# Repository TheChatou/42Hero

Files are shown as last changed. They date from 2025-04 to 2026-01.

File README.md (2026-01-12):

# 42Hero  
*Borne d’arcade rythmique embarquée — jeu physique, musique 8-bit, fabrication réelle.*
<p align="center">
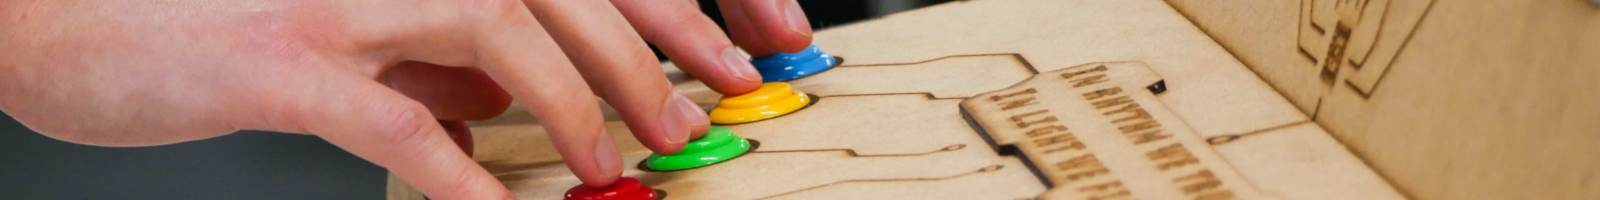
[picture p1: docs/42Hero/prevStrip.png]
  
</p>
---

## 42Hero ?

42Hero est né au sein du **LabElec (42Chips)**, à l’occasion de la grande soirée d’inauguration du nouveau campus **42 Paris – 42Up**.

Lors d’une réunion du Lab, plusieurs idées de projets sont évoquées.  
Je n’ai, en théorie, pas le temps de m’engager sur un projet hors cursus.  
Mais cette idée-là reste sans volontaire.

Je lève la main.  
Puis, dans la semaine, deux camarades me rejoignent. Le projet est lancé.

L’idée est simple :  
prendre l’ADN de **Guitar Hero** et l’adapter à un **format arcade physique**, sans écran.

42Hero est une **mini-borne d’arcade rythmique deux joueurs**, conçue pour une seule chose :  
être **jouable immédiatement**, sans explication, sans friction.

- jouable en quelques secondes  
- lisible sans tutoriel  
- robuste face à un vrai public  
- amusante à jouer *et* à regarder  

La boucle de jeu est volontairement minimale :

> **appuyer au bon moment → voir et entendre immédiatement le résultat**

Aucune interface graphique, aucun menu complexe :  
tout passe par le **son**, les **LEDs** et le **rythme**.

Le projet met l’accent sur l’**expérience utilisateur physique**, la synchronisation temps réel et la fiabilité — pas sur une complexité logicielle décorative.

---

## Mon rôle & implications techniques

42Hero est un **projet embarqué de l’École 42**, réalisé en équipe de trois, avec une contrainte simple et brutale :  
**une deadline réelle, du public, et zéro droit à l’erreur visible**.

J’ai assuré une **grande partie de la direction technique et de l’expérience de jeu**, avec un objectif clair :  
**livrer une borne stable, lisible et fun**, pas un prototype “qui marche chez moi”.

Mon rôle a couvert :

- **Direction de conception de la borne** (forme, ergonomie, lisibilité)
- **Logique centrale de gameplay** (states, scoring, timing)
- **Système musical embarqué** : adaptation / réécriture de morceaux et intégration microcontrôleur
- **UX physique** : boutons, feedback LEDs, rythme, compréhension instantanée
- **Fabrication & intégration** : itérations, contraintes matérielles, tests réels

Ce projet a impliqué un **investissement massif sur une période courte**, au prix d’une quasi mise en pause de mon cursus commun — choix discutable, mais formateur.

En résumé :  
du **frontend**, sans écran, avec des fils, de la soudure…  
et une deadline qui ne négociait pas.

---

## Aperçu — Une vraie borne, pas une démo

<p align="center">
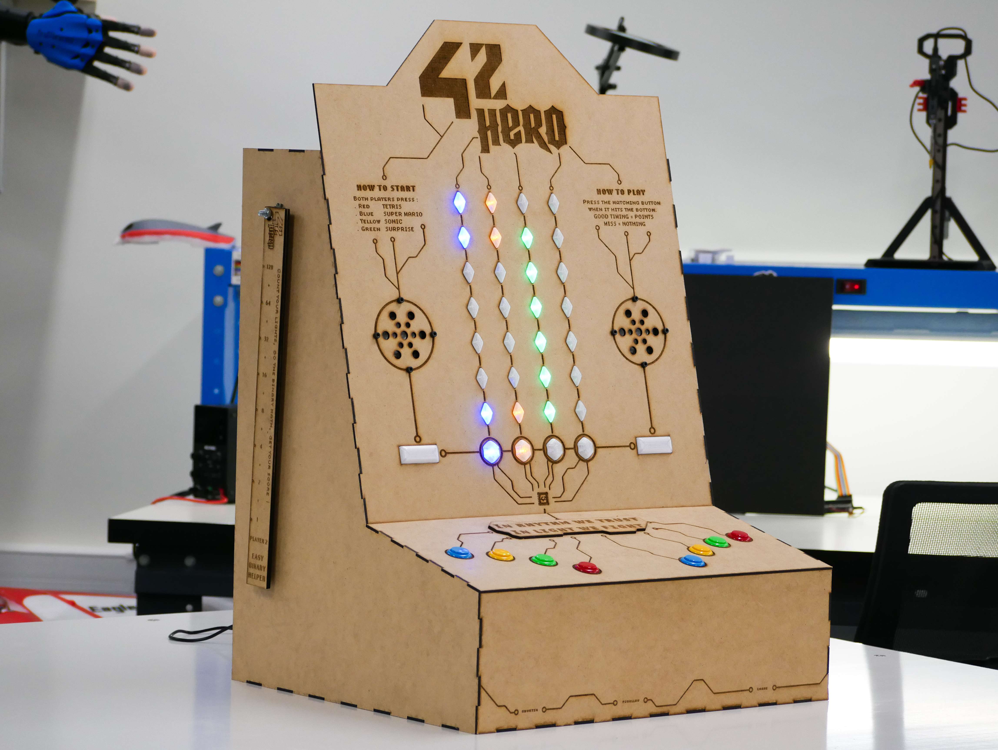
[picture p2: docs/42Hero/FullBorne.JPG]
  
  <br>
  <em>Build final — compact, lisible, et prêt à encaisser de vrais joueurs.</em>
</p>

La borne a été conçue pour un contexte réel :  
inauguration, public varié, peu de temps pour expliquer.

Chaque choix répond à la même question :  
**“Est-ce que quelqu’un comprend et joue en moins de 10 secondes ?”**

---

## Gameplay — Du rythme lisible, avec feedback physique

<p align="center">
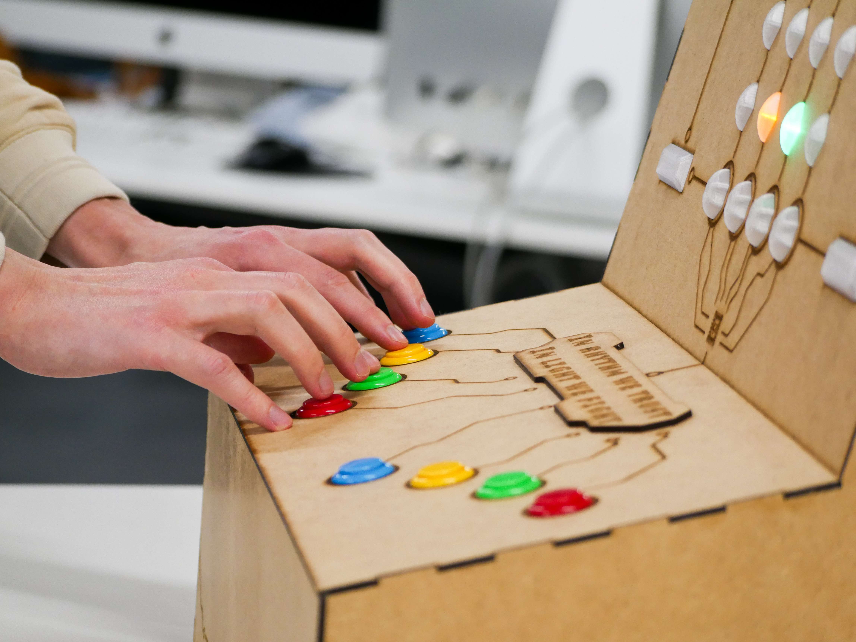
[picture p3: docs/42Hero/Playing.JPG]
  
  <br>
  <em>Contrôles physiques + feedback LED : réponse immédiate, sans écran pour tricher.</em>
</p>

Le gameplay repose sur :

- une **boucle rythmique claire**
- une **logique d’états stricte**
- un **feedback instantané** (LEDs + son)

En embarqué, le timing n’est pas un détail :  
c’est **le cœur du jeu**.

Sans écran, toute la lisibilité passe par :
- la disposition physique
- le rythme visuel des LEDs
- la synchronisation sonore avec les actions du joueur

---

## Musique — Polyphonie 8-bit sur microcontrôleur

<p align="center">
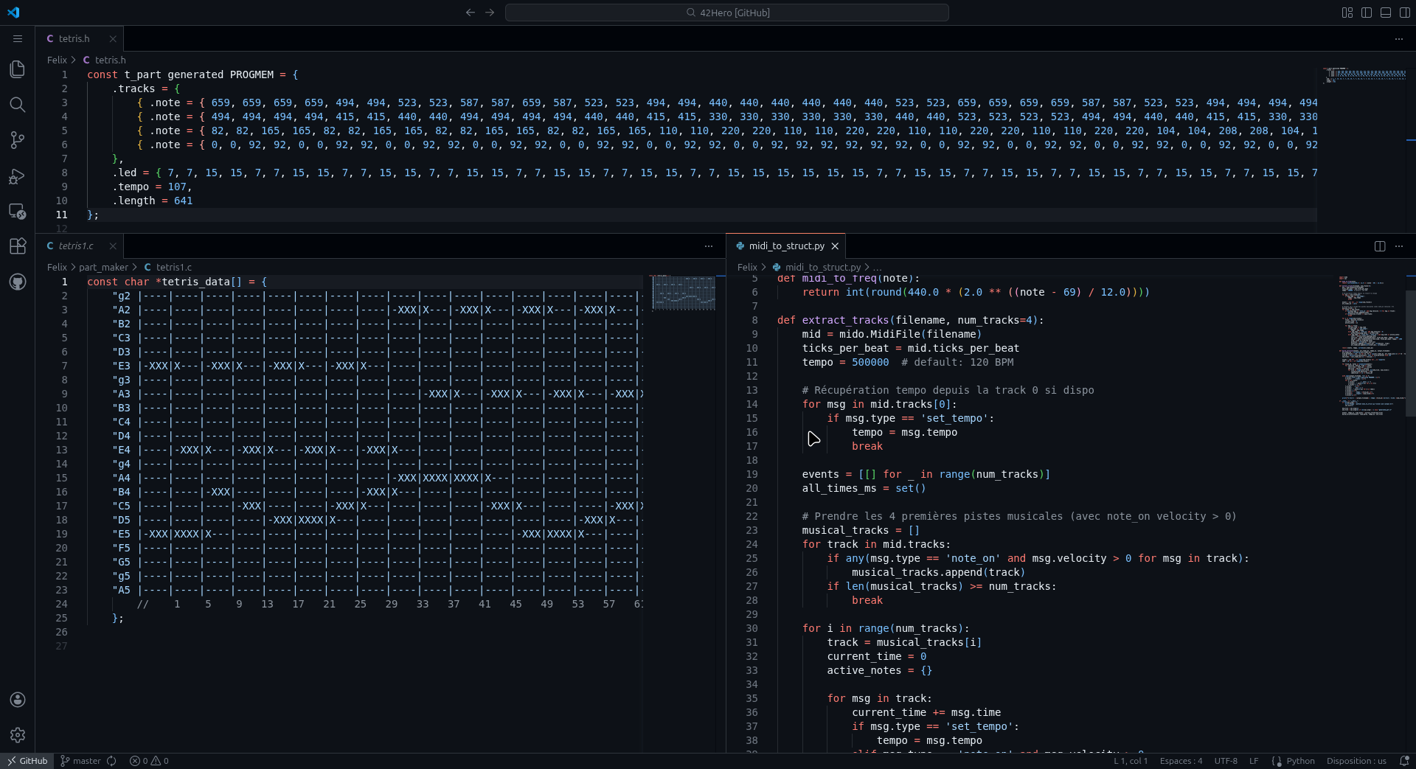
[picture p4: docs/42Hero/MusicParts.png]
  
  <br>
  <em>Réécriture de morceaux : la musique doit “rentrer” dans le microcontrôleur.</em>
</p>

La musique n’est pas un simple habillage :  
elle structure entièrement le gameplay.

- Réécriture de morceaux “jeu vidéo” en **partitions compatibles microcontrôleur**
- Lecture **polyphonique** via plusieurs timers hardware
- Synchronisation précise avec les événements de jeu

Ici, pas de piste audio pré-enregistrée :  
ce sont les **timers** qui pilotent le rythme et le feedback.

---

## Design & fabrication — Modélisation 3D pour le monde réel

<p align="center">
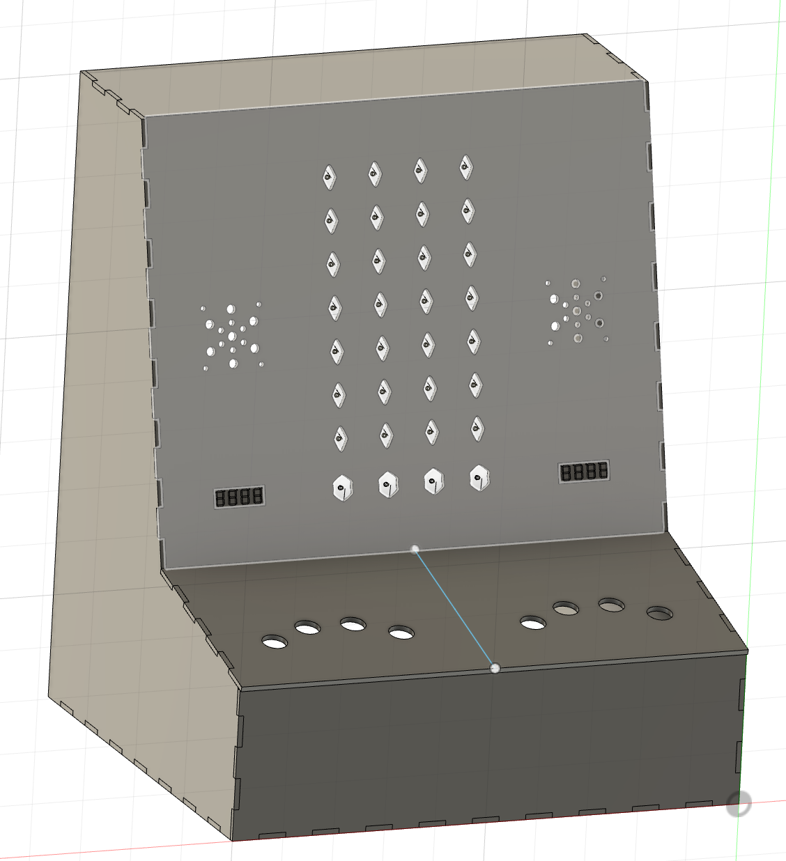
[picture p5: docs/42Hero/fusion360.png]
  
  <br>
  <em>Fusion 360 — design contraint par de vraies pièces, pas par un mockup.</em>
</p>

Pour obtenir une borne propre et assemblable :

- Modélisation complète sur **Fusion 360**
- Préparation des pièces pour **découpe laser** et **impression 3D**
- Itérations sur les tolérances, l’assemblage et l’intégration des composants

<p align="center">
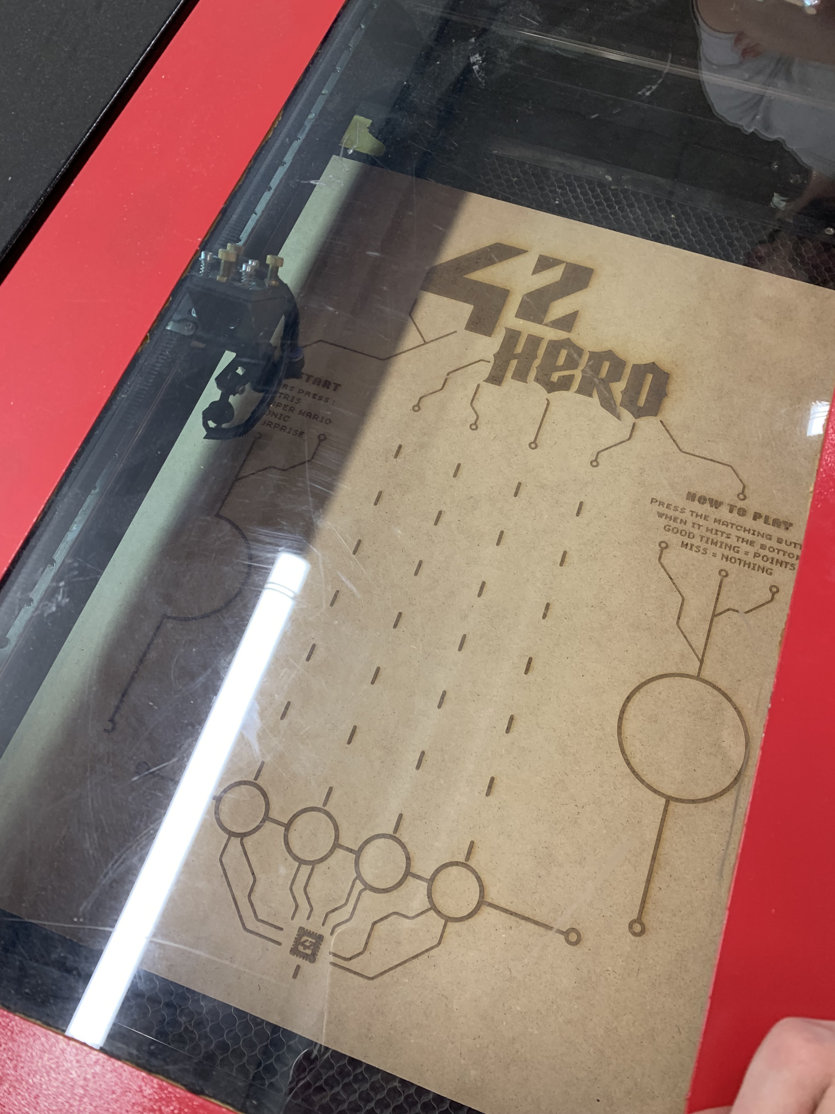
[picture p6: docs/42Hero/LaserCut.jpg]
  
  <br>
  <em>Du CAD au réel : là où les tolérances commencent à discuter.</em>
</p>

---

## Embarqué & intégration — Câbler, souder, débugger

<p align="center">
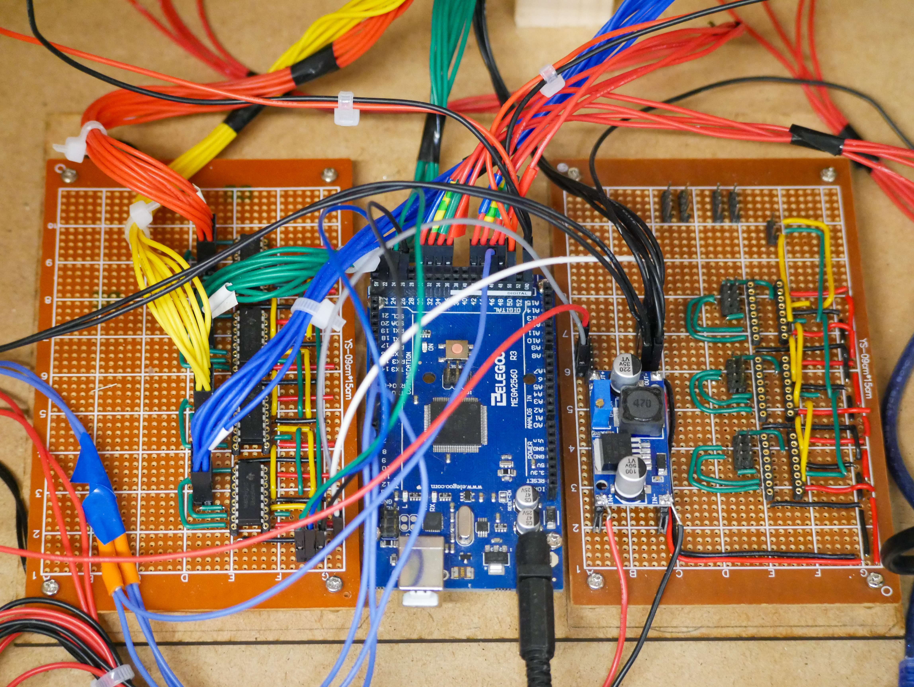
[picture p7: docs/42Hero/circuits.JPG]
  
  <br>
  <em>Câblage et soudure : l’embarqué sans filtre.</em>
</p>

Une grande partie du projet est très **hands-on** :

- câblage
- soudure
- routage
- debug de bugs… qui n’existent que dans le monde réel

Ici, pas de démo sur breadboard :  
tout doit **tenir**, **fonctionner**, et **rester stable**.

---

## Deadline & arbitrages — Livrer sous contrainte

<p align="center">
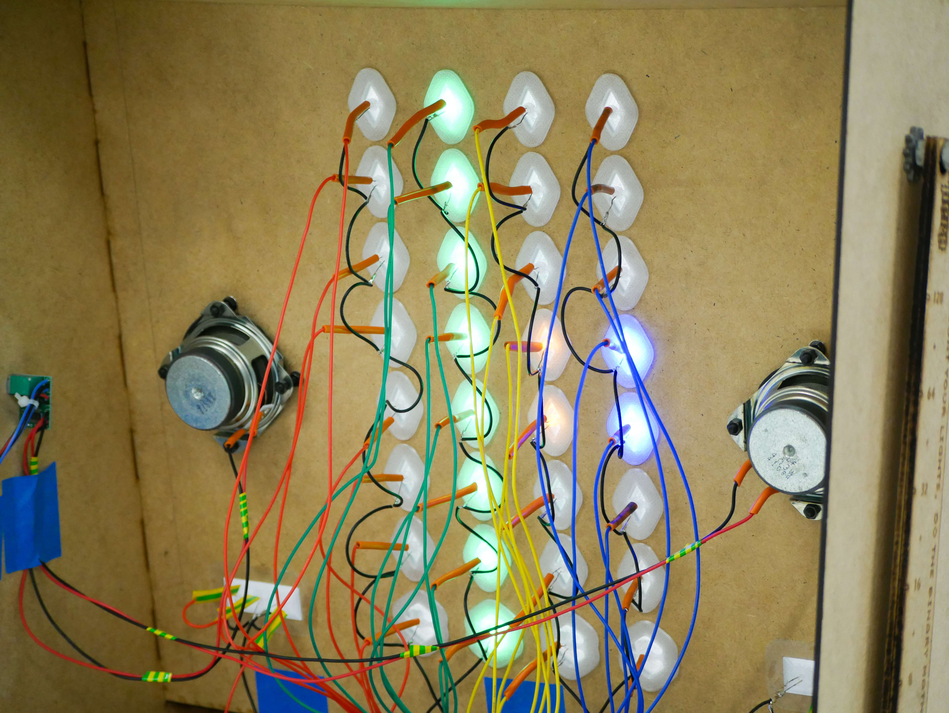
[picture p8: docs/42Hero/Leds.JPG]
  
  <br>
  <em>Le payoff : du gameplay stable en conditions réelles.</em>
</p>

La deadline d’inauguration a imposé des choix pragmatiques :

- abandon tardif de l’affichage 7-segments initialement prévu
- simplification du système de score
- priorité absolue à la **jouabilité** et à la **fiabilité**

Un vrai projet, ce n’est pas tout garder.  
C’est **savoir quoi sacrifier pour livrer quelque chose qui marche**.

---

## Tech stack

- **Microcontrôleur** : Arduino
- **Audio** : polyphonie via timers hardware
- **Électronique** : boutons, LEDs, amplification
- **Fabrication** : découpe laser, impression 3D
- **CAD** : Fusion 360

---

## Collaborateurs

<table align="center">
  <tr>
    <td align="center">
      <a href="https://github.com/LouisMahe"><strong>LouisMahe</strong></a>
    </td>
    <td align="center">
      <a href="https://github.com/Geouf91"><strong>Geouf91</strong></a>
    </td>
  </tr>
  <tr>
    <td align="center">
      <a href="https://github.com/LouisMahe">
        
      </a>
    </td>
    <td align="center">
      <a href="https://github.com/Geouf91">
        
      </a>
    </td>
  </tr>
</table>

<p align="center">
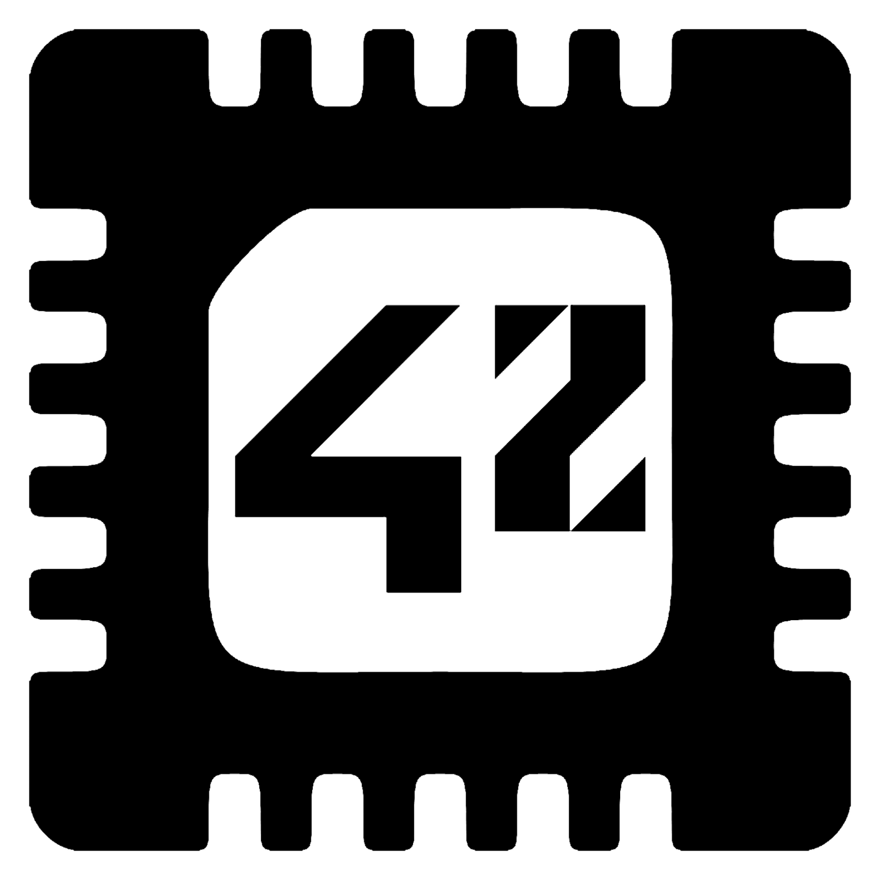
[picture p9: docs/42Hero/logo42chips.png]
42Chips - LabElec
  
</p>

<p align="center">
  <em>
    Merci au LabElec (42Chips) et à toutes celles et ceux qui ont soutenu,
    encouragé et rendu ce projet possible.
  </em>
</p>

---

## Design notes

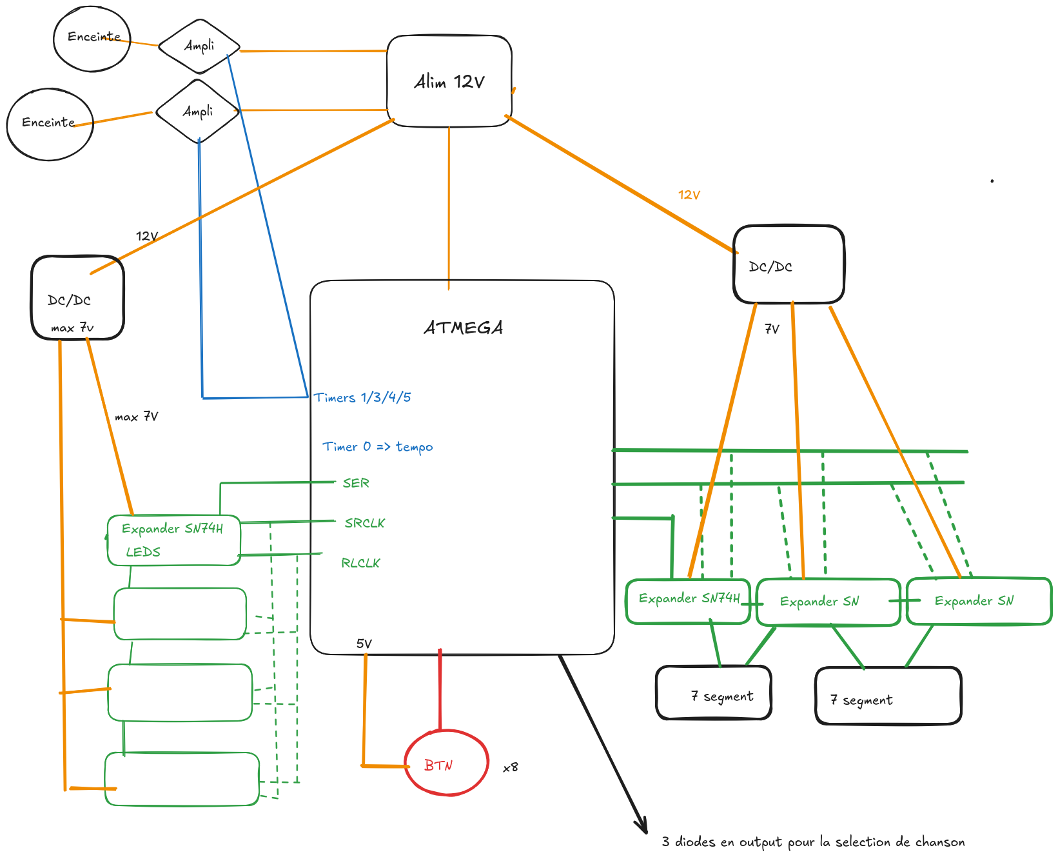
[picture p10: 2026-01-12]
42_hero_concept.png

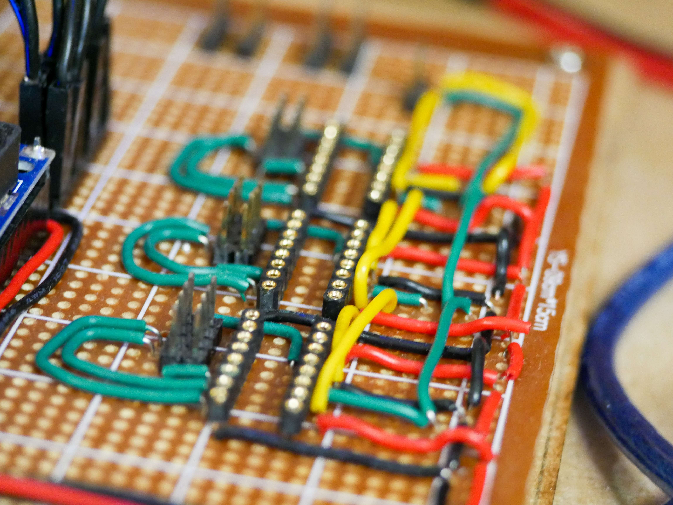
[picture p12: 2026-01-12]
docs/42Hero/circuitsCloseUp.JPG

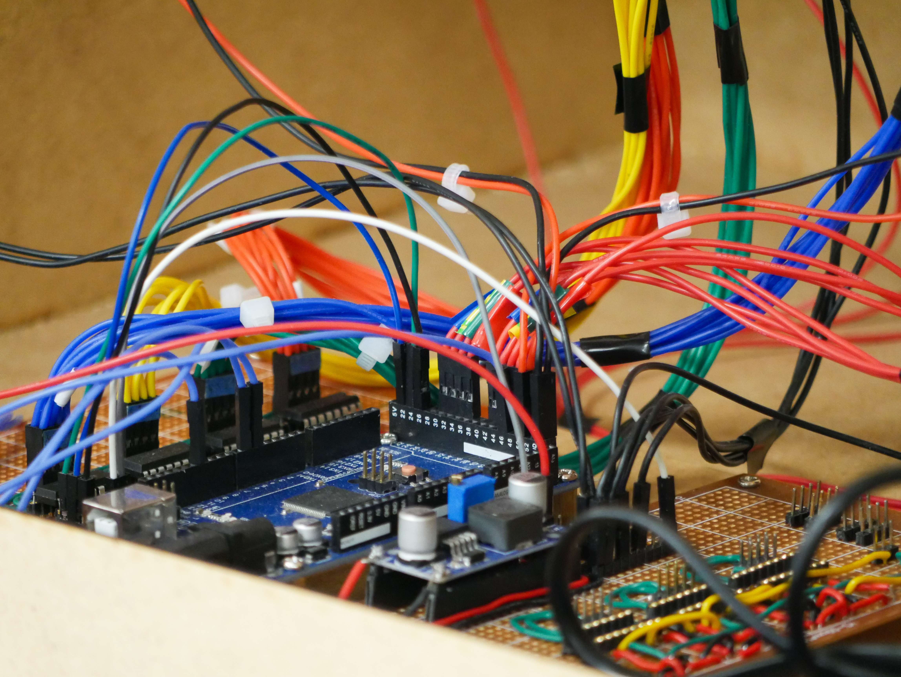
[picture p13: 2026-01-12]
docs/42Hero/circuitsCloseUp2.JPG

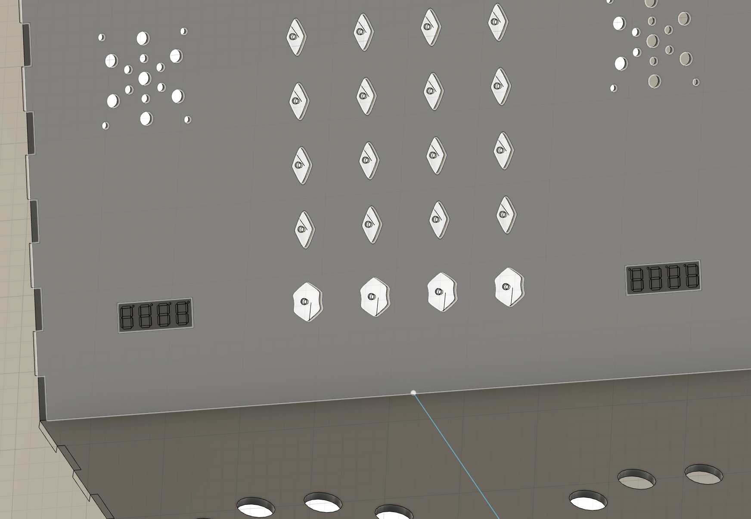
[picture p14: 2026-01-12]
docs/42Hero/fusio360CloseUp.png

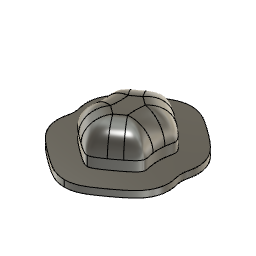
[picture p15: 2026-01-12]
docs/42Hero/Diffuseur5.png

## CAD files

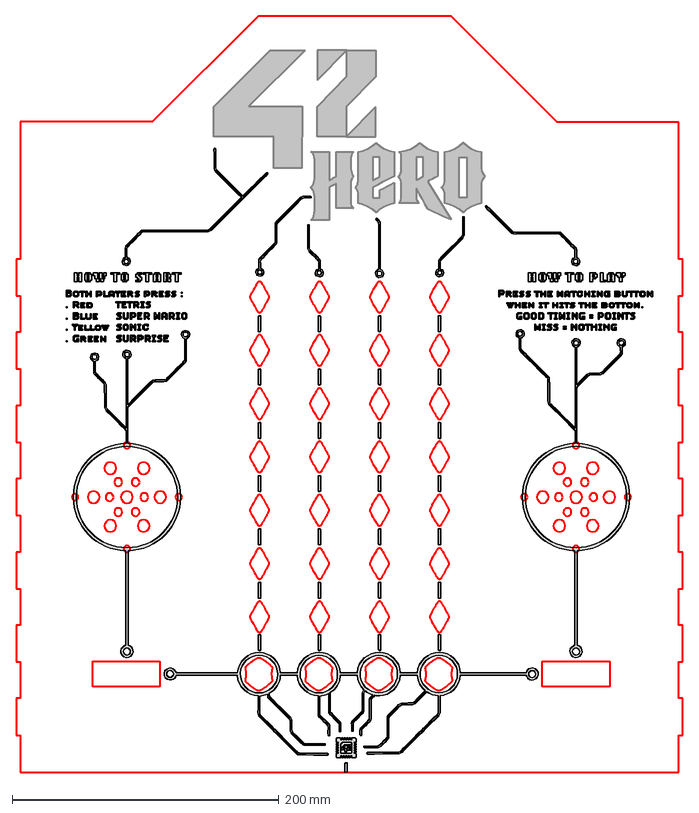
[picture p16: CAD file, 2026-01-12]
dxf_files/front.dxf
500.0 x 568.0 mm

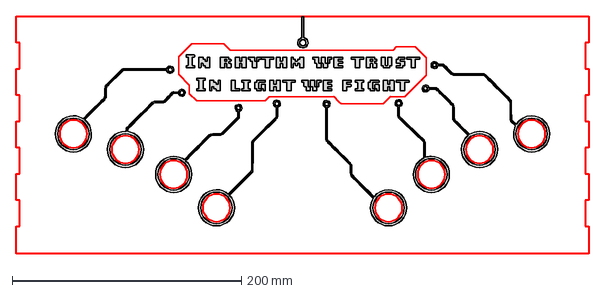
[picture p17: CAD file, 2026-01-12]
dxf_files/front_bottom.dxf
500.0 x 207.2 mm

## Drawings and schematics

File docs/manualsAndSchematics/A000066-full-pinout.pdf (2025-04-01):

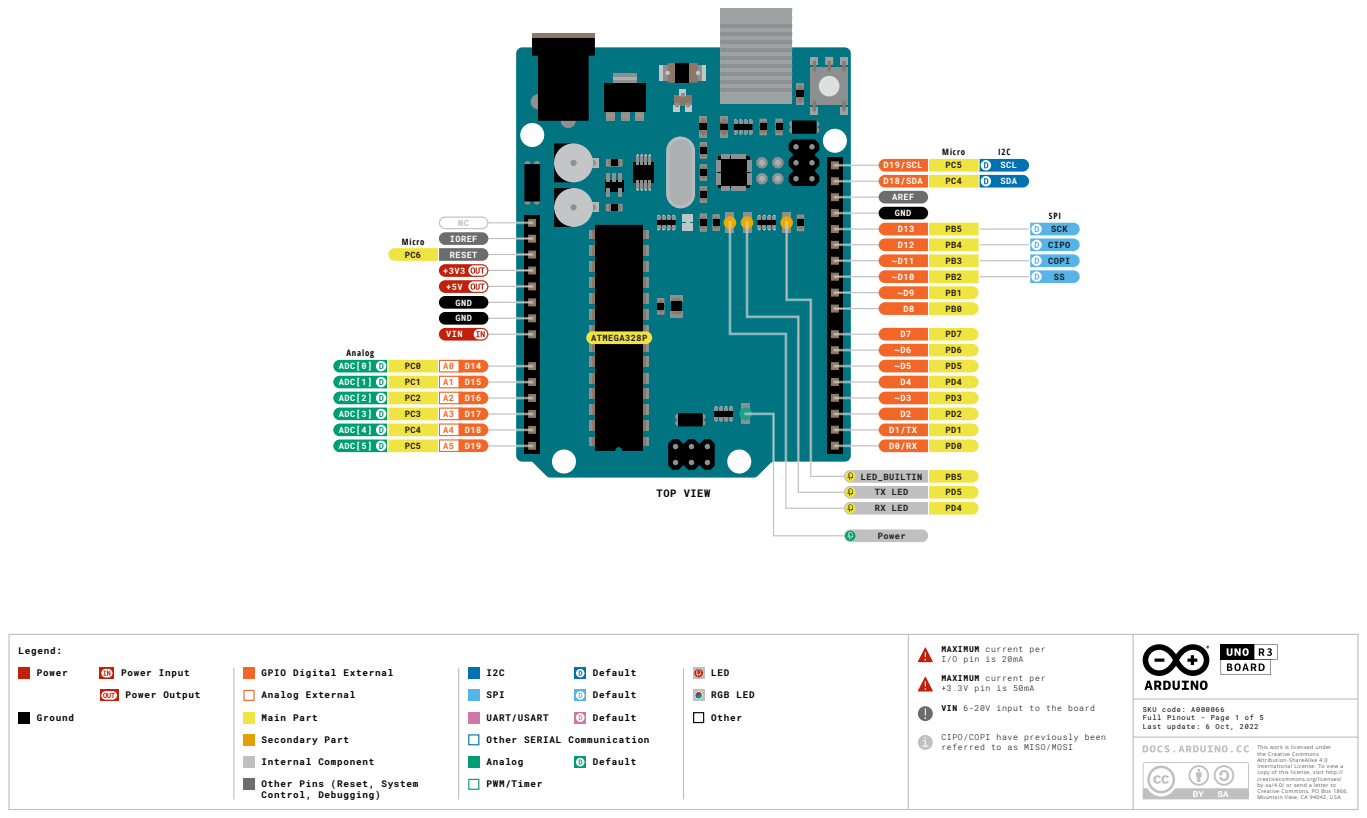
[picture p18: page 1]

PC2 | A2
PC3 | A3

MAXIMUM current per
I/O pin is 20mA
+3.3V pin is 50mA
VIN 6-20V input to the board

GPIO Digital External
Analog External
Main Part
Secondary Part
Internal Component
Other Pins (Reset, System
Control, Debugging)

SKU code: A000066
Full Pinout - Page 1 of 5
Last update: 6 Oct, 2022

CIPO/COPI have previously been
referred to as MISO/MOSI

This work is licensed under
the Creative Commons
Attribution-ShareAlike 4.0
International License. To view a
copy of this license, visit http://
creativecommons.org/licenses/
by-sa/4.0/ or send a letter to
Creative Commons, PO Box 1866,
Mountain View, CA 94042, USA.

# WARNING!

# Advanced Section

# The following information is for advanced use only and may not be officially supported by Arduino software

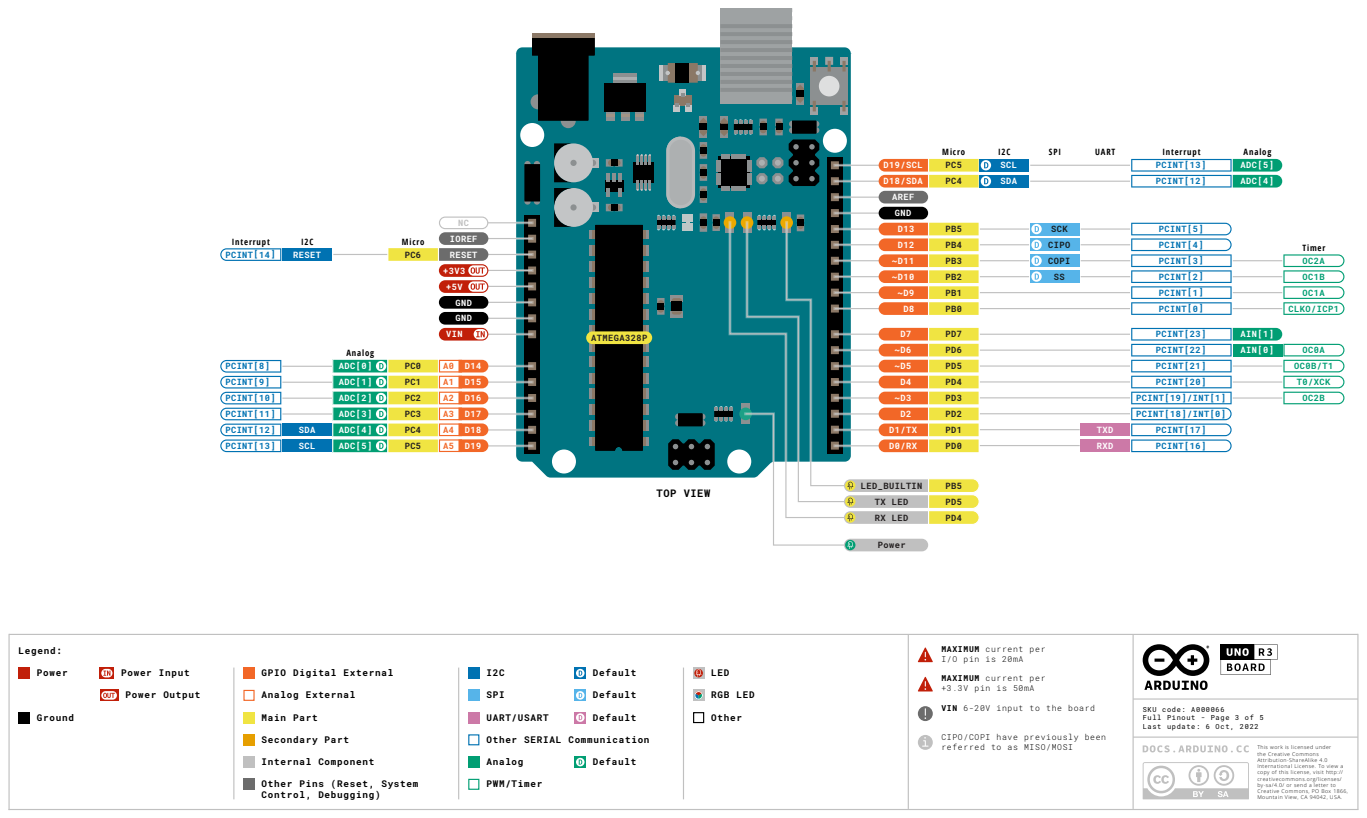
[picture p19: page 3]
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

SKU code: A000066
Full Pinout - Page 3 of 5
Last update: 6 Oct, 2022

CIPO/COPI have previously been

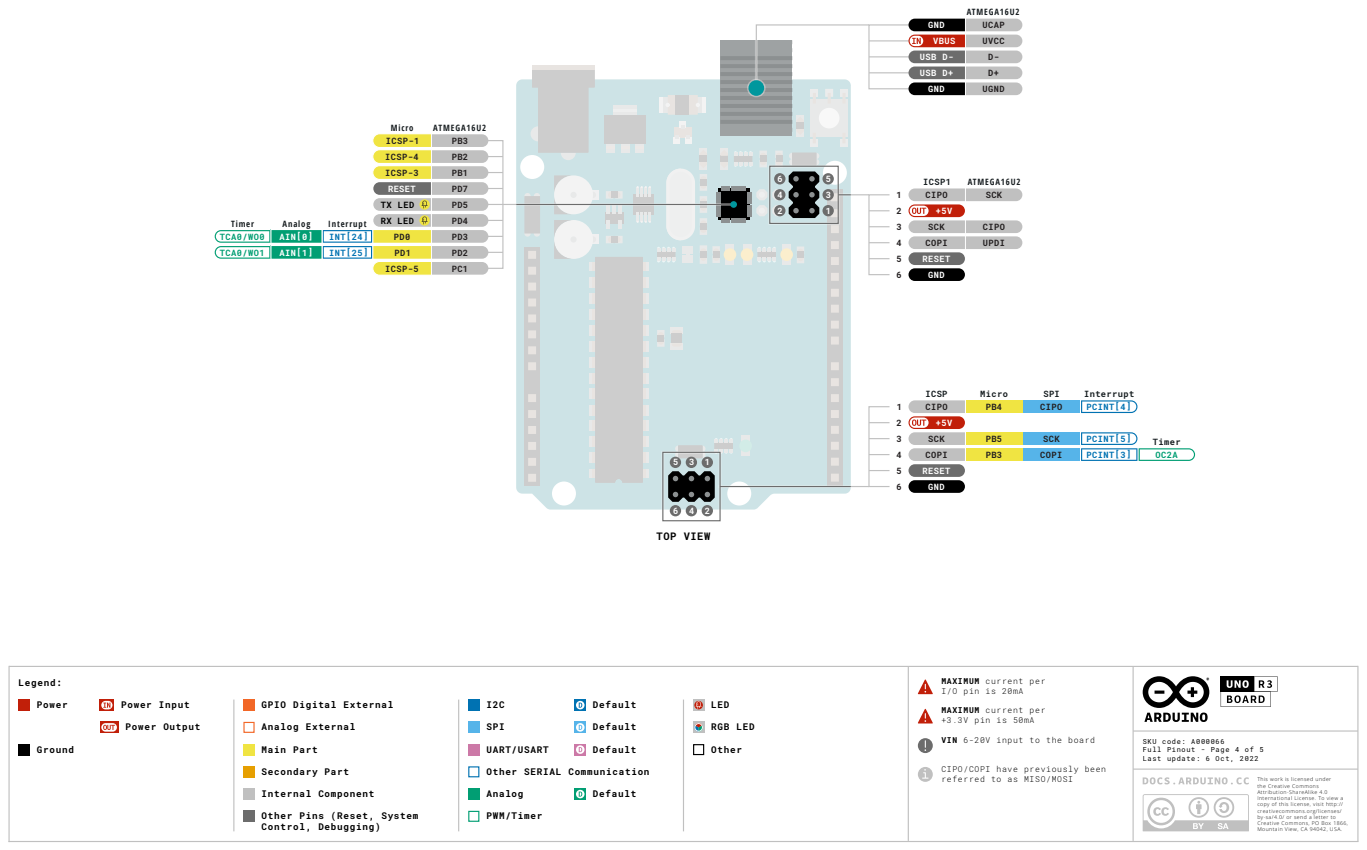
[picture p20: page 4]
Legend:; Power; Power Input; Power Output; Ground; Default; SPI; UART/USART; LED; RGB LED; Other; TOP VIEW; Micro; ATMEGA16U2; Timer; Analog; Interrupt; TCA0/WO0 TCA0/WO1; ICSP-1 ICSP-4 ICSP-3 RESET TX LED RX LED PD0 PD1 ICSP-5; INT[24] INT[25]; AIN[0] AIN[1]; SCK; CIPO UPDI; 1 CIPO 2 +5V 3 SCK 4 COPI 5 RESET 6 GND; ICSP1; ICSP; CIPO; COPI; PCINT[4]; PCINT[5] PCINT[3]; GND; UCAP; VBUS; UVCC; USB D-; USB D+; UGND

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

GPIO Digital External
Analog External
Main Part
Secondary Part

Other SERIAL Communication

SKU code: A000066
Full Pinout - Page 4 of 5
Last update: 6 Oct, 2022

CIPO/COPI have previously been

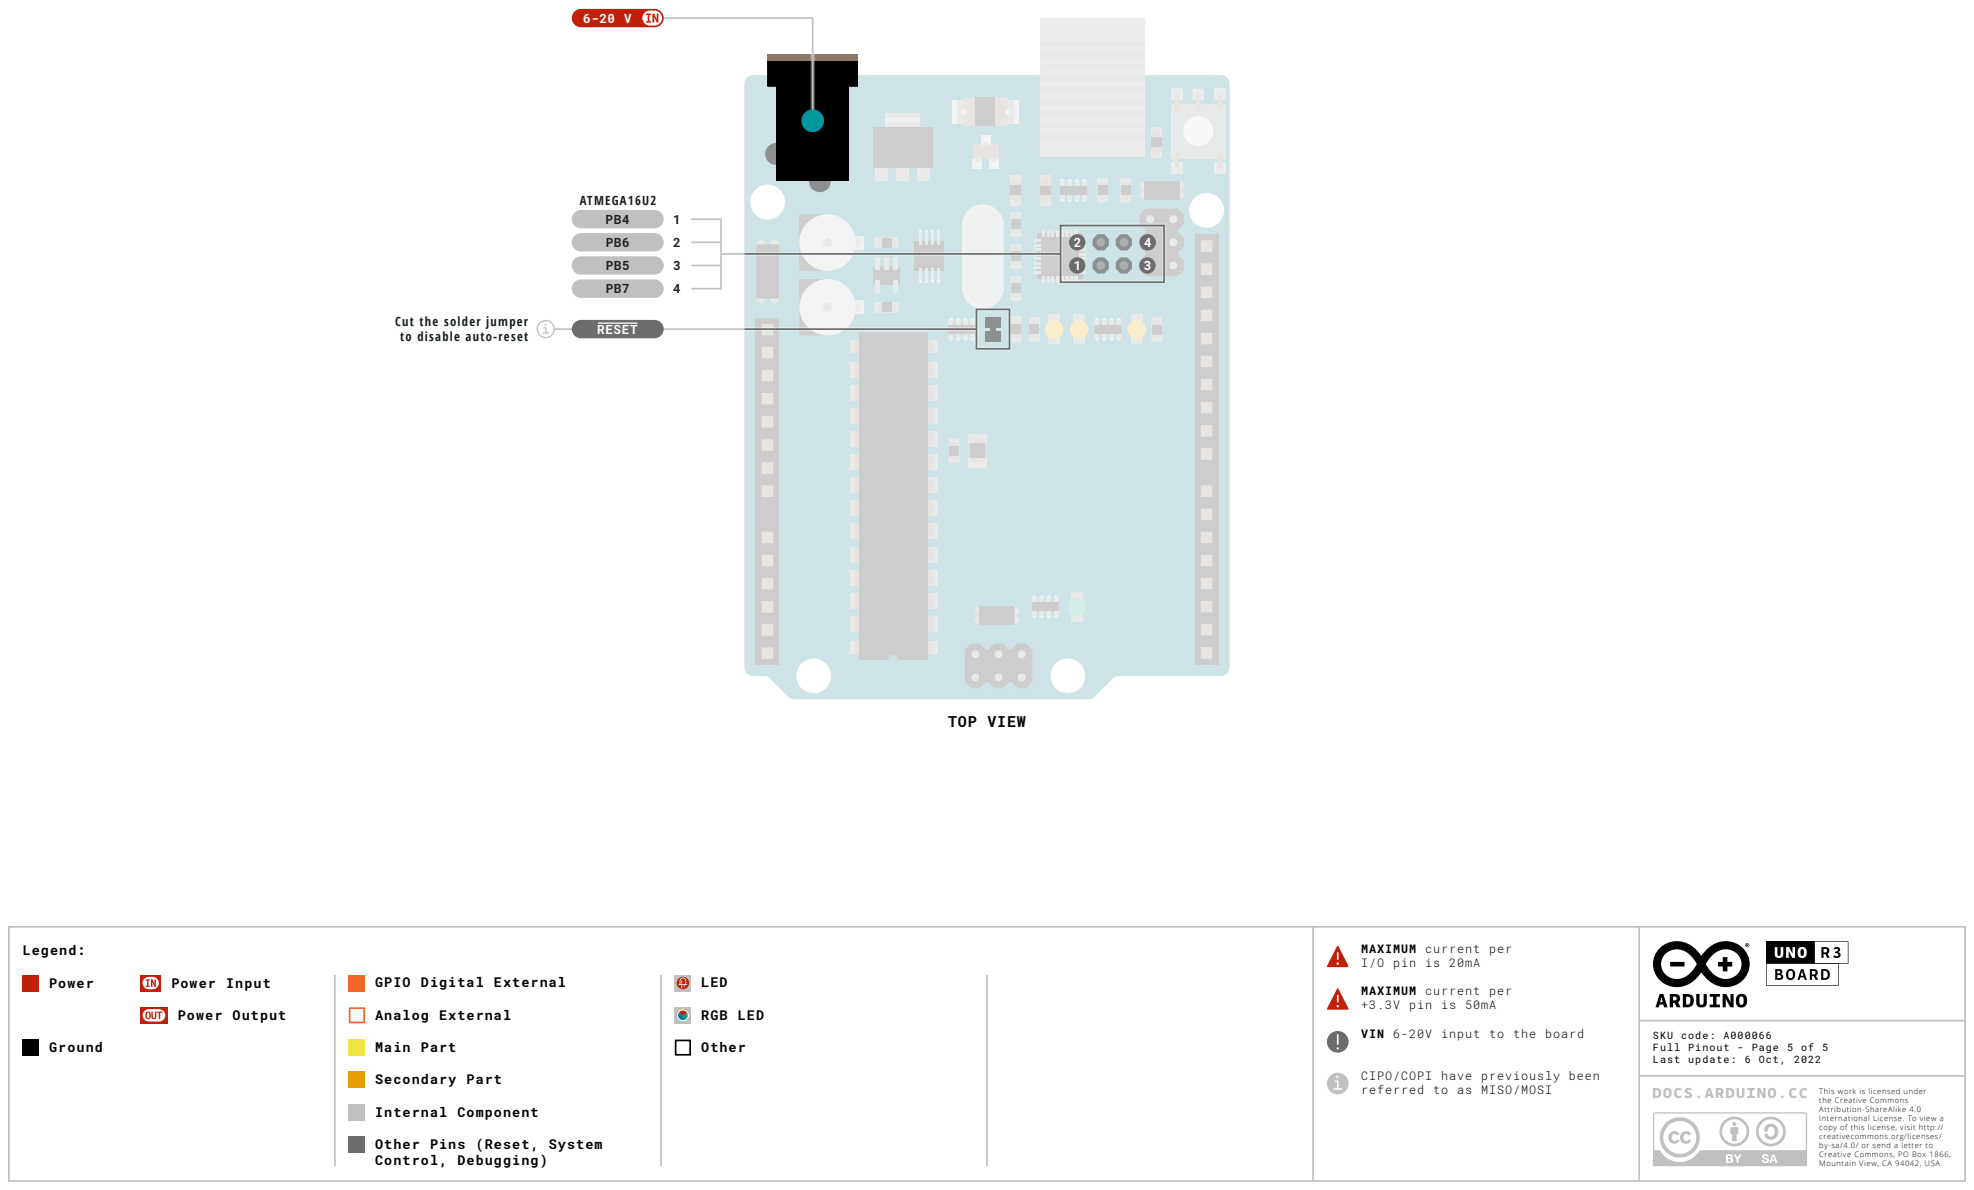
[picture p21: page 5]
Legend:; Power; Power Input; Power Output; Ground; LED; RGB LED; Other; TOP VIEW; ATMEGA16U2 PB4 PB6 PB5 PB7; RESET

Cut the solder jumper
to disable auto-reset

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

GPIO Digital External
Analog External
Main Part
Secondary Part

SKU code: A000066
Full Pinout - Page 5 of 5
Last update: 6 Oct, 2022

CIPO/COPI have previously been

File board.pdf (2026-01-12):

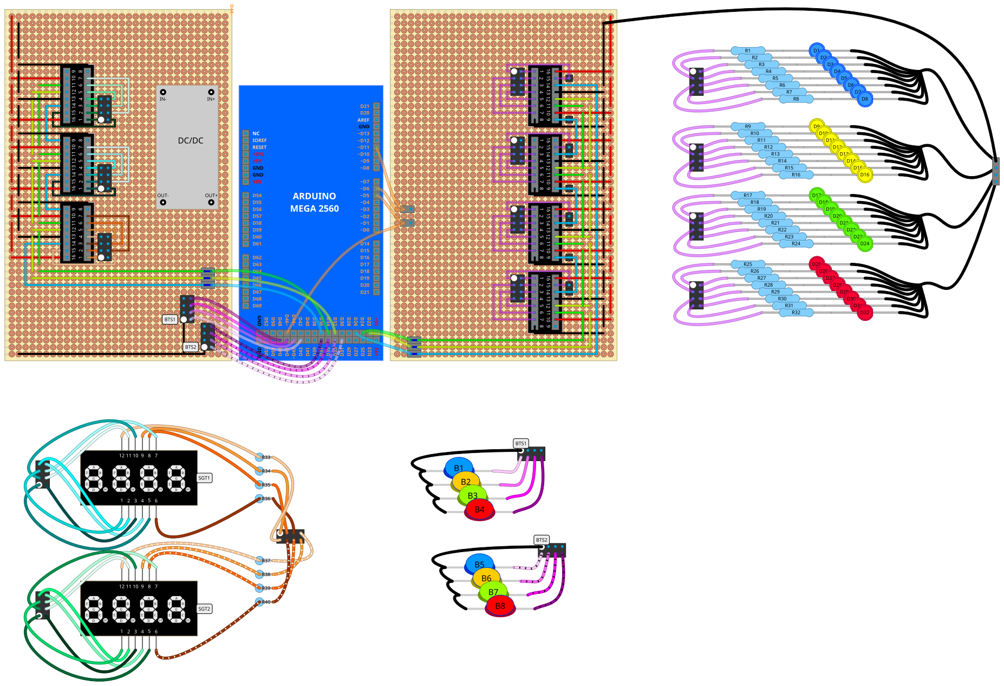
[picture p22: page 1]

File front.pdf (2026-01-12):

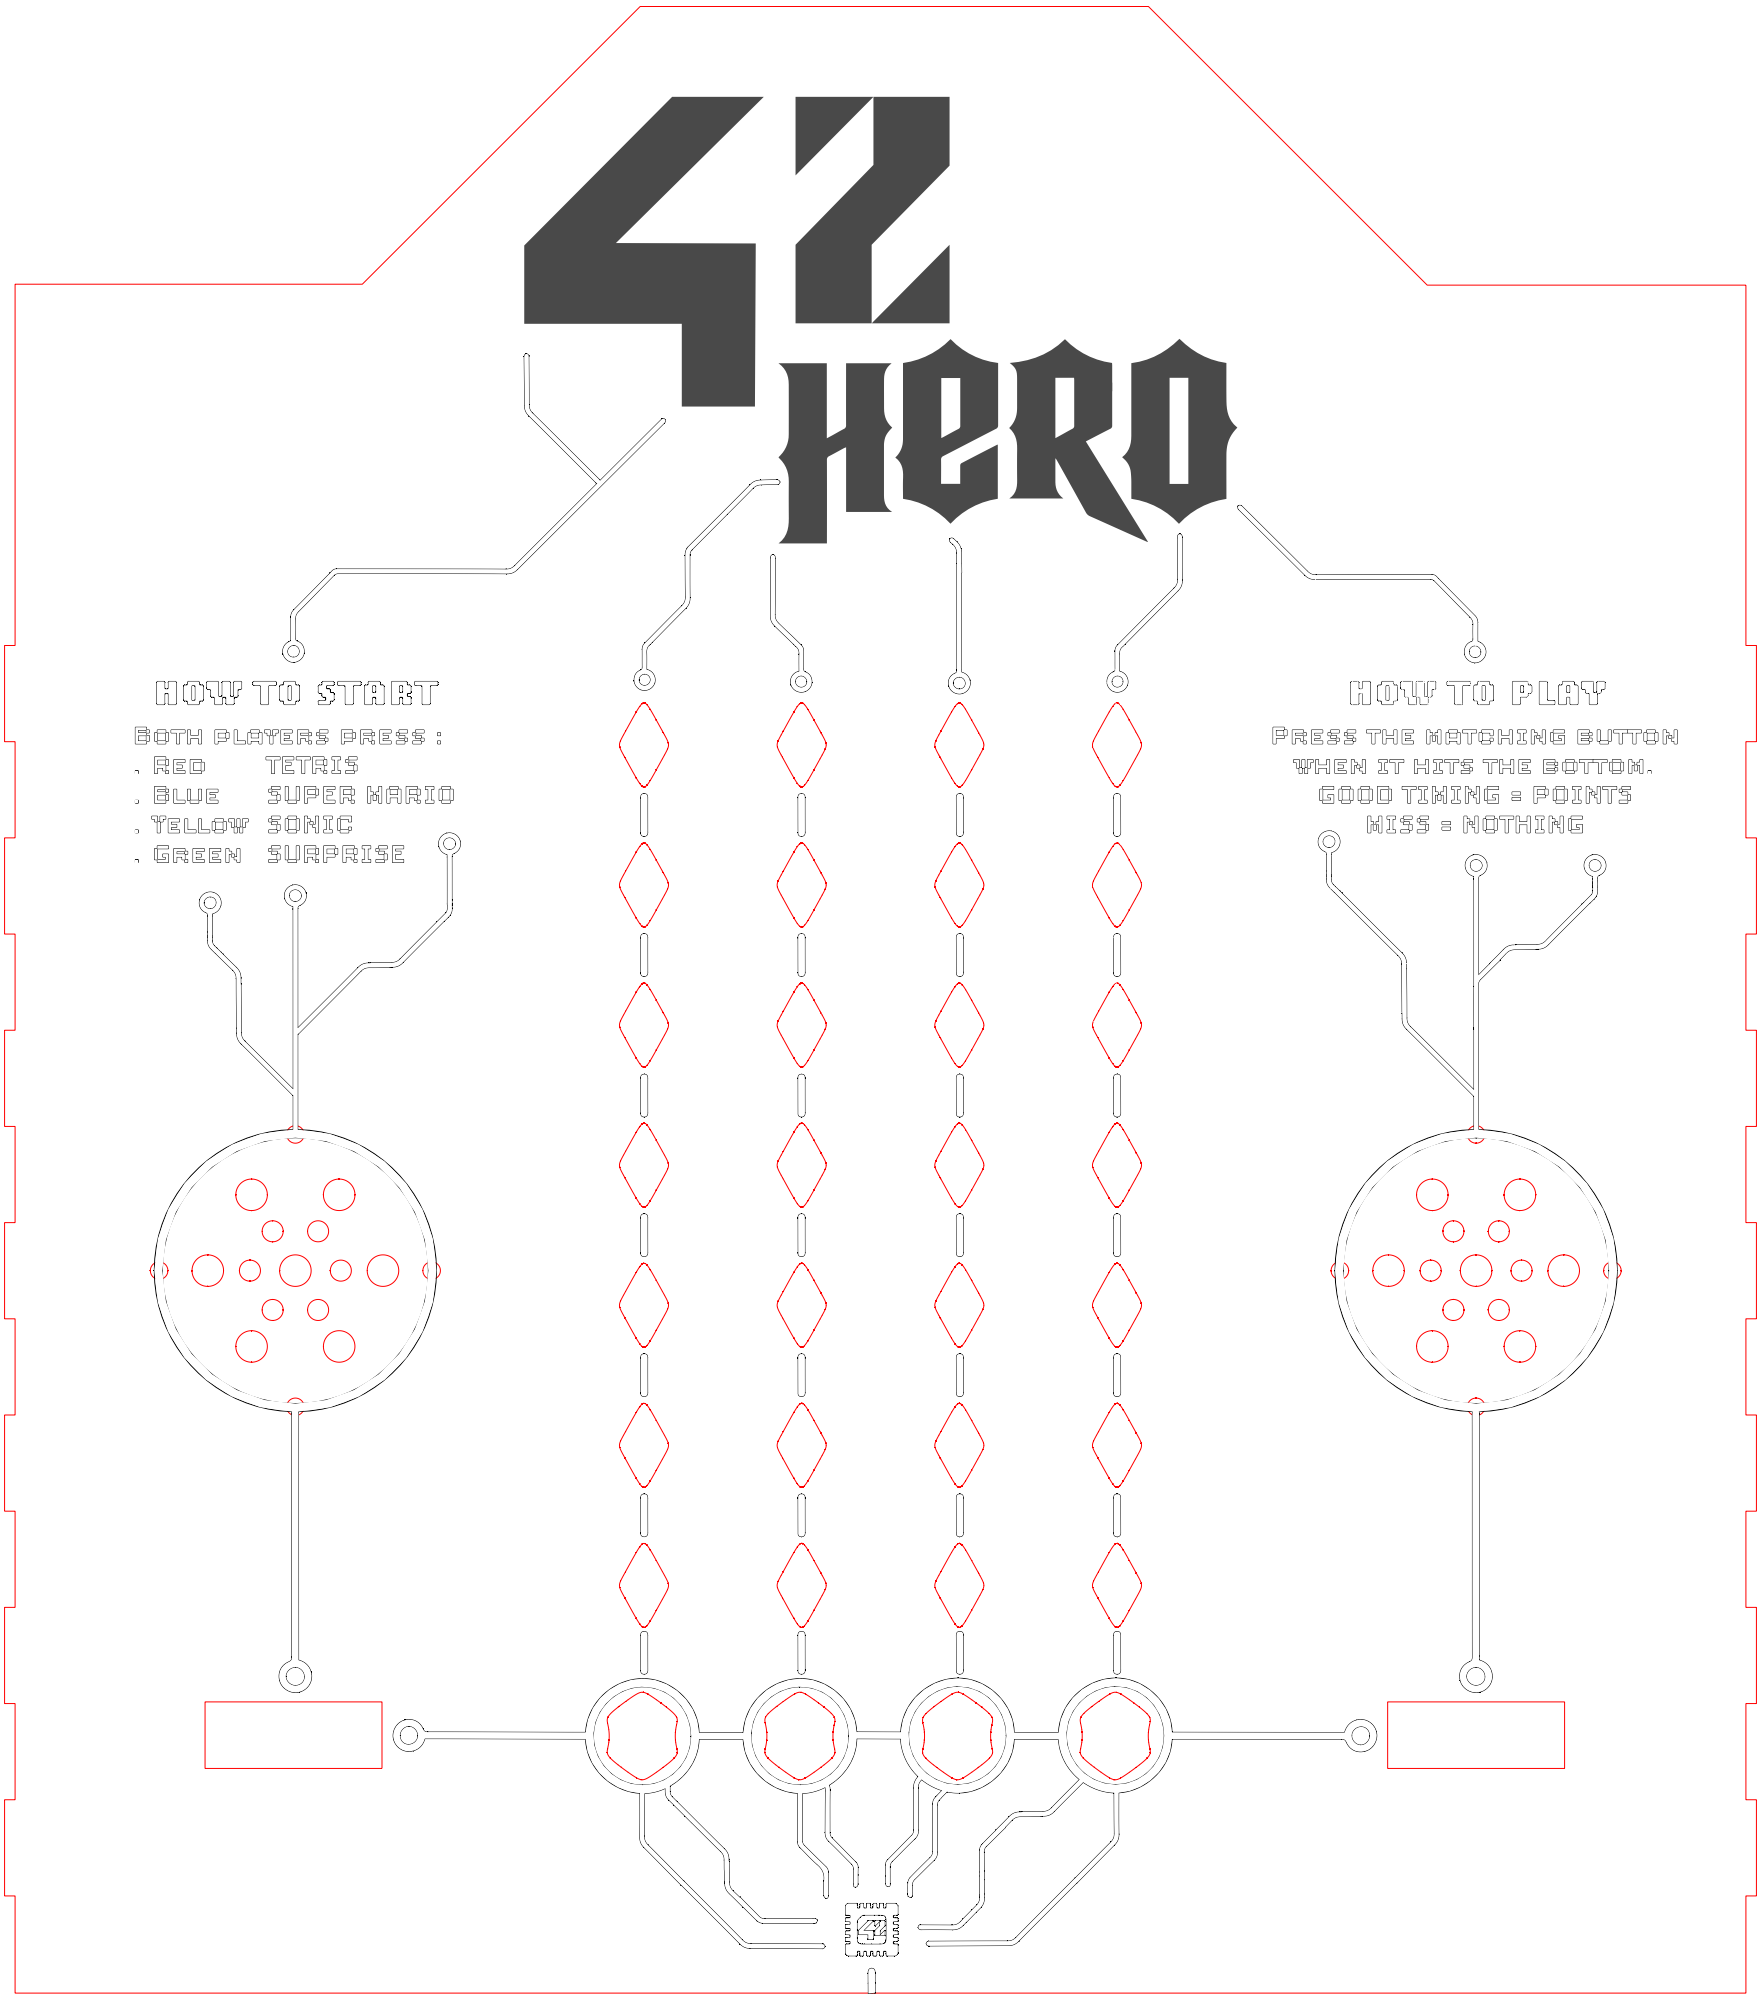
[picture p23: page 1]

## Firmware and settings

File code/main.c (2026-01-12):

#include "hero.h"
#include "text_to_led.h"
#include "parts.h"
#include "zelda.h"
#include "mario.h"
#include "tetris.h"
#include "sonic.h"

// counter incremented by master timer to update state machine
volatile uint16_t   tc0_counter;

extern volatile Expander exp_leds;

//vectors to store button measures
volatile    uint8_t button_left[4] = {0,0,0,0};
volatile    uint8_t button_right[4] = {0,0,0,0};

//vectors to store player input from button measures
volatile    uint8_t pushed_left[4] = {0,0,0,0};
volatile    uint8_t pushed_right[4] = {0,0,0,0};

volatile    uint16_t    tempo = 0;
volatile    uint8_t     state = PLAY;

volatile    uint8_t led_logo[4] = {0, 0, 0, 0};

/// @brief play next time from the part
/// @param music the partition
/// @param curr_note index of the current time in the arrays
void    play_tracks(const t_part *music, uint16_t curr_note)
{
    notes_timers_init();

 
    play_note_with_timer(pgm_read_word(&music->tracks[0].note[curr_note]), 0);
    play_note_with_timer(pgm_read_word(&music->tracks[1].note[curr_note]), 1);
    play_note_with_timer(pgm_read_word(&music->tracks[2].note[curr_note]), 2);
    play_note_with_timer(pgm_read_word(&music->tracks[3].note[curr_note]), 3);
      
    tc0_counter = 0; // reset counter to 0
    TCNT2 = 0;
}

//master timer:
// play the notes, update the state-engine status to trigger input measuremen/comparison
// right now each event is base on a proportion of the music's tempo which is not that great
ISR(TIMER0_COMPA_vect)
{
    if (state == IDLE)
        return;
    tc0_counter++; // increase counter
    if (tc0_counter == tempo) // one cycle completed
    {
        tc0_counter = 0;
        state = PLAY; // time to play next note
    }
    else if (tc0_counter == (3*tempo / 4)){ //starting to accept inout for next note
        state = INPUT_AHEAD;
    }
    else if (tc0_counter == (tempo / 4)){ // end of input-window => match input/part and score
        state = UPDATE_SCORE;
    }
    else if (tc0_counter == (tempo / 2)) // turn off success leds
    {
        PORTB &= ~( (1 << VALID_LEFT) | (1 << VALID_RIGHT));
    }
}

/// @brief store the state of buttons in the vectors
inline  void    measure_buttons()
{
    button_left[0] = !(PINC & (1 << PC6));
    button_left[1] = !(PINC & (1 << PC4));
    button_left[2] = !(PINC & (1 << PC2));
    button_left[3] = !(PINC & (1 << PC0));   
    button_right[0] = !(PINL & (1 << PL6));
    button_right[1] = !(PINL & (1 << PL4));
    button_right[2] = !(PINL & (1 << PL2));
    button_right[3] = !(PINL & (1 << PL0));
}

/// @brief main game loop: state driven see comments inside
/// @param p the music to play
void    play_song( const t_part *p)
{
    const t_part    *music = p;
    const   uint16_t    length = pgm_read_word(&music->length);
    volatile uint16_t    time = 0; // partition idx counter
    tempo = pgm_read_word(&music->tempo);

    volatile    uint16_t   left_score = 0;
    volatile    uint16_t    right_score = 0;

    volatile    uint8_t leds[4] = {0, 0, 0, 0};
    volatile    uint8_t target[4] = {0,0,0,0};

    volatile uint16_t   best = 0; // compute the perfect score to display score as a gauge

    state = PLAY;
    turn_leds_off();
    _delay_ms(1000);
    while(time <= length)
    {
        measure_buttons();
        if (state == PLAY) //time to play note
        {

            play_tracks(music, time);
            // update led
            uint8_t new_led = pgm_read_byte(&music->led[time]);
            uint16_t diff[2];
            diff[0] = pgm_read_word(&music->diff[0]);
            diff[1] = pgm_read_word(&music->diff[1]);
            // to ease the game only a fraction of note can be taken as leds and button input
            // eg : one note out of four has to be played by the player for tetris
            if ((time % diff[0]) != diff[1])
                new_led = 0;
            // set the led according to the part
            for (uint8_t i = 0; i < 4; i++)
            {
                if (new_led & (1 << i))
                {
                    leds[i] = (leds[i] >> 1) | 0b10000000;
                }
                else{
                    leds[i] = leds[i] >> 1;
                }
            }
            shiftLane(&exp_leds, leds, 4);
            // register the target for the player input
            target[0] = leds[0] & 1;
            target[1] = leds[1] & 1;
            target[2] = leds[2] & 1;
            target[3] = leds[3] & 1;
            time++; // increase idx counter
            state = INPUT_AFTER; // state update : accept player inputs 
        }
        else if (state == UPDATE_SCORE) // compare players input against the target
        {
            uint8_t left_delta = compare(target, pushed_left);
            uint8_t right_delta = compare(target, pushed_right);
            if (left_delta == 2) // if player is correct and button were to be pushed => score
            {
                PORTB |= 1 << VALID_LEFT;
                left_score += 1;
            }
            if (right_delta == 2)
            {
                PORTB |= 1 << VALID_RIGHT;
                right_score += 1;
            }
            if (target[0] | target[1] | target[2] | target[3]) // compute perfect score
                best += 1;
            state = WAIT; //update state : just wait while the notes play
            reset(pushed_left);
            reset(pushed_right);
        }
        if (state > WAIT) // in all state above WAIT the player input are taken into account
        {
            // we take into account a button pushed
            for (uint8_t i = 0; i < 4; i++)
            {
                pushed_left[i] |= button_left[i];
                pushed_right[i] |= button_right[i];
            }
            // set pushed vars
        }
        // condition to stop te song by pushing all buttons, disable in release mode!
        if (button_left[3] && button_right[3] && 
            button_left[2] && button_right[2] &&
            button_left[1] && button_right[1] &&
            button_left[0] && button_right[0])
        {
            timers_stop();
            return;
        }
    }
    // end of song time to compute score
    timers_stop();
    state = IDLE;
    PORTB &= ~((1 << VALID_LEFT) | (1 << VALID_RIGHT));

    //score as percentage of perfect score
    uint8_t final_left = gauge((left_score * 100) / (best));
    uint8_t final_right = gauge((right_score*100) / (best));
    uint8_t score_display[4] = {final_left, 0, 0, final_right};
    
    //display winner side
    if (left_score > right_score)
        PORTB |= 1 << VALID_LEFT;
    else
        PORTB |= 1 << VALID_RIGHT;
    shiftLane(&exp_leds, score_display, 4);

    _delay_ms(5000);
    turn_leds_off();
    //score in binary
    uint8_t as_bit_left = (left_score*255)/best;
    uint8_t as_bit_right = (right_score*255)/best;
    score_display[0] = as_bit_left;
    score_display[3] = as_bit_right;
    shiftLane(&exp_leds, score_display, 4);
    _delay_ms(10000);
    PORTB &= ~((1 << VALID_LEFT) | (1 << VALID_RIGHT));
}

/// @brief waiting screen displaying 42 hero on the leds, interrupt when correct button input pressed
/// @return 
int playing_logo()
{
    static uint8_t current_char = 0;
    static uint32_t timer = 0;
    
    measure_buttons();

    // go back to track selection if a button was pressed
    for (uint8_t i = 0; i < 4; i++)
        if (button_left[i] && button_right[i])
            return 0;

    if (++timer >= 40000)
    {
        timer = 0;

        for (uint8_t row = 0; row < 4; row++)
        {
            led_logo[row] = pgm_read_byte(&logo_hero[current_char][row]);
            // led_logo[row] = pgm_read_byte(&alphabet[0][row]);
        }

        shiftLane(&exp_leds, led_logo, 4);
        current_char = (current_char + 1) % LOGO_SIZE;
    }

    return 1;
}

int main(void)
{
    sei();
    init();
    turn_leds_off();
    turn_leds_on();
    while(1)
    {
        measure_buttons();
        while (playing_logo());
        // song is chosen by each player pushing the same button
        if (button_left[3] && button_right[3])
        {
            play_song(&tetris_test);
            turn_leds_off();
            turn_leds_on();
        }
        else if (button_left[0] && button_right[0])
        {
            play_song(&mario_test);
            turn_leds_off();
            turn_leds_on();
        }
        else if (button_left[1] && button_right[1])
        {
            play_song(&sonic);
            turn_leds_off();
            turn_leds_on();
        }
        else if (button_left[2] && button_right[2])
        {
            play_song(&zelda);
            turn_leds_off();
            turn_leds_on();
        }
        
        _delay_ms(300);
    }
}

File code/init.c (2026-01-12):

#include "init.h"

void    master_timer_init()
{
    TCCR0B |= (1 << CS01) | (1 << CS00); //prescaler == 64
    TCCR0A = (1 << WGM01); // mode == CTC
    TIMSK0 |= 1 << OCIE0A; //interrupt on compare match
    OCR0A = 100;
}

/// @brief notes are played using 4 timers (4 notes polyphony)
/// timers comapare is set according the the desired frequency and will output a square note
void    notes_timers_init()
{
    TCCR1B |= 1 << CS11; // prescaler == 8
    
    //timer mode fast PWM with top = ICR
    TCCR1B |= (1 << WGM12)  | (1 << WGM13);
    TCCR1A |= (1 << WGM11);

    TCCR1A |= (1 << COM1A1); //clear OC1A on compare match, set it at bottom
    DDRB |= (1 << PB5); //OC1A == PB5 as output
    ICR1 = 0;
    OCR1A = 0;

    //timer 3
    TCCR3B |= 1 << CS31;
    TCCR3B |= (1 << WGM32) | (1 << WGM33);
    TCCR3A |= (1 << WGM31);
    TCCR3A |= (1 << COM3A1);
    DDRE |= (1 << PE3);
    ICR3 = 0;
    OCR3A = 0;

    //timer 4
    TCCR4B |= 1 << CS41;
    TCCR4B |= (1 << WGM42) | (1 << WGM43);
    TCCR4A |= (1 << WGM41);
    TCCR4A |= (1 << COM4A1);
    DDRH |= (1 << PH3);
    ICR4 = 0;
    OCR4A = 0;

    //timer 5
    TCCR5B |= 1 << CS51;
    TCCR5B |= (1 << WGM52) | (1 << WGM53);
    TCCR5A |= (1 << WGM51);
    TCCR5A |= (1 << COM5A1);
    DDRL |= (1 << PL3);
    ICR5 = 0;
    OCR5A = 0;
}




void    init()
{
    DDRB |= (1 << PB1); // TIMER0
    DDRB |= (1 << PB5); // TIMER1 ---------- D11 ------- OK
    DDRE |= (1 << PE3); // TIMER3 ---------- D5 ------- OK
    DDRH |= (1 << PH3); // TIMER4 ---------- D6 ------- OK
    DDRL |= (1 << PL3); // TIMER5 ---------- D46 ------ OK

    DDRA |= (1 << PA4) | (1 << PA0) | (1 << PA2) | (1 << PA6); //leds_exp
    DDRC &= ~(0b01010101); //buttons
    DDRL &= ~(0b01010101); //buttons
    PORTA = 0;
    PORTC |= 0b01010101; //buttons
    PORTL |= 0b01010101; // buttons

    DDRB |= 1 << PB2; //left
    DDRB |= 1 << PB3; //right

    master_timer_init();
    notes_timers_init();

}

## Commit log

2025-04-07 timers, begining
2025-04-08 tetris led sheet based on tetris data sheet
2025-04-08 test d'une partition avec les LEDs
2025-04-21 led + button
2025-04-21 Ca Avance les partitions et les timers
    [pyvenv.cfg]
2025-04-21 Ca Avance les partitions et les timers Et Mario maintenant
2025-04-22 Start new with ATMega2560
    [Exemple_Demande de dépense.xlsx, LED Matrix commande.xlsx, arcade.dxf]
2025-05-17 polyphonie done, les headers de mon main fonctionnent tous et sont au format lisible pour la polyphonie
2025-05-27 struct pour leds
2025-05-28 led expander kicad, 7 segment working
    [42Hero.kicad_sch]
2025-06-18 leds + music OK
2025-06-19 white led for winner
2026-01-12 clean (merci Louis), et ajouts de docs et du README
    [42Hero.kicad_sch, Exemple_Demande de dépense.xlsx, LED Matrix commande.xlsx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]
